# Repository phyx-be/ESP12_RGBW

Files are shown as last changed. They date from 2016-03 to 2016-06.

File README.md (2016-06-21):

# ESP12_RGBW
An ESP12 based RGBW light module using onboard LEDs or capable of controlling external LEDs.

## Rev 00

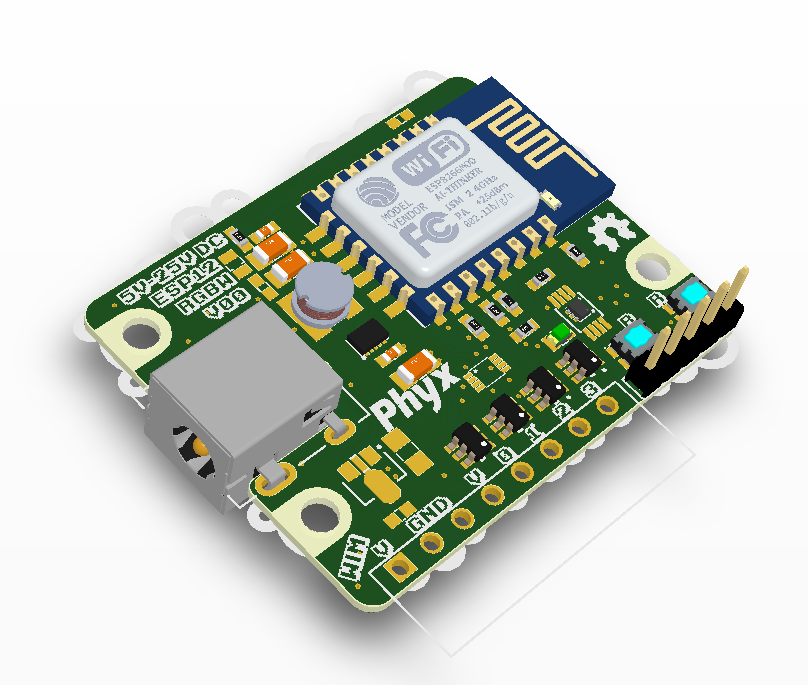
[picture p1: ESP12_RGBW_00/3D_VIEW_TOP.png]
ESP12_RGBW_00_T

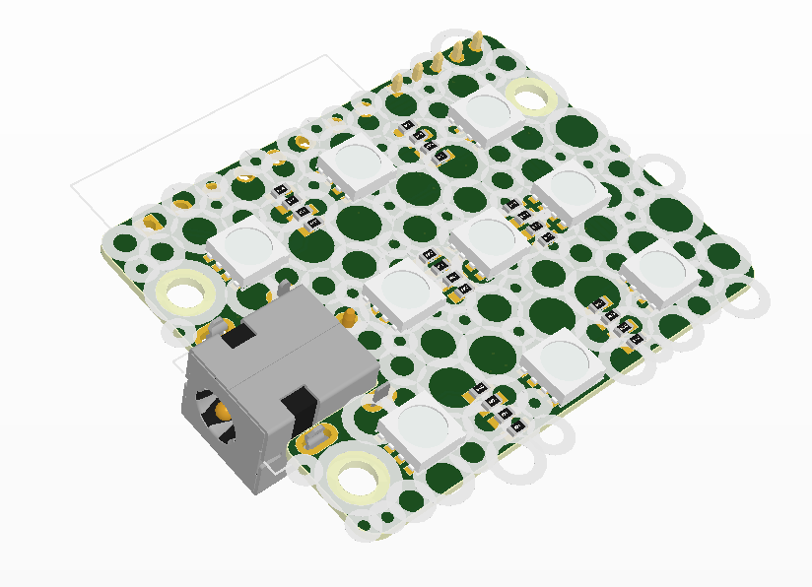
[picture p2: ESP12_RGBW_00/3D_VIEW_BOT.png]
ESP12_RGBW_00_B


### Features

A list of the basic features for the intended use of this board.

- 3V3 level FTDI-compatible UART pin header
- miniature push buttons for reset and boot
- Wide input DC-DC converter (input voltage ranging from 5V to 26V DC)
- 4 FETs capable of sinking 4A
- 3 strings of 3 RGBW LEDs each on the bottom side

### Variants

The board has some options, beside the default configuration with the internal LEDs, which allows you to use the same board for different projects. You'll notice an option for a temperature sensor, bi-directional buffer and pluggable terminal block. More info regarding these options are listed below.

#### Internal LEDs

Default use with either 3, 6 or 9 RGBW LEDs soldered on the bottom side of the PCB. Requires a 12V DC power source. Don't forget to double the resistor values hen using 10mA RGBW LEDs instead of the 20mA LEDs as intended.

#### External LED strips

If you want to drive external RGB or RGBW LED strip you'll have to solder the pluggable terminal block for and you don't need to solder the DC jack and the internal LEDs. If you do opt for a combination of internal and external LEDs, don't forget to match the working voltage of both. By default the internal LEDs require a working voltage of 12V DC.

#### Temperature sensor

You can choose either a 1-Wire [DS18B20](http://www.maximintegrated.com/en/products/analog/sensors-and-sensor-interface/DS18B20.html) temperature sensor or a I2C controlled [Ti TMP112](http://www.ti.com/product/TMP112) temperature sensor. The TMP112 has an higher accuracy.

#### Bi-directional buffer.

Soldering the dual channel bi-directional buffer [TXB0102](http://www.ti.com/product/txb0102) makes it possible for the board to control digital LED strips and strings. This buffer requires a 5V reference which can be created by an internal 5V LDO or by supplying the board with 5V and placing a 0R resistor over the input and output pin of the LDO. Using this option you can no longer add the T1 and T2 FETs, hereby loosing 2 PWM or I/O channels.

## Rev 01

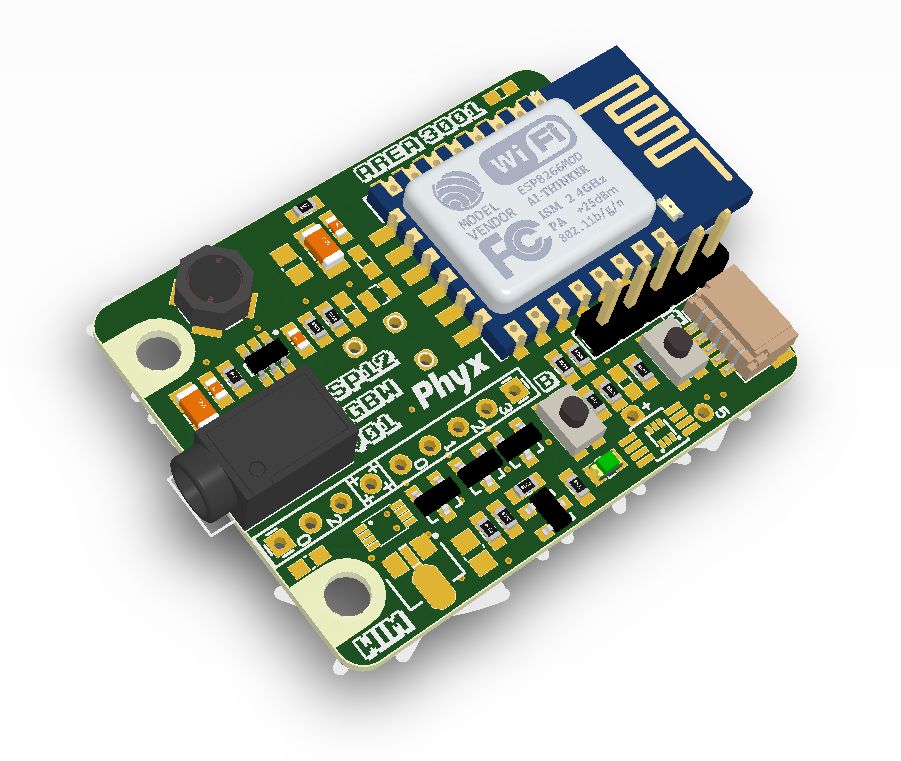
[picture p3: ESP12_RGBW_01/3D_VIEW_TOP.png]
ESP12_RGBW_01_T

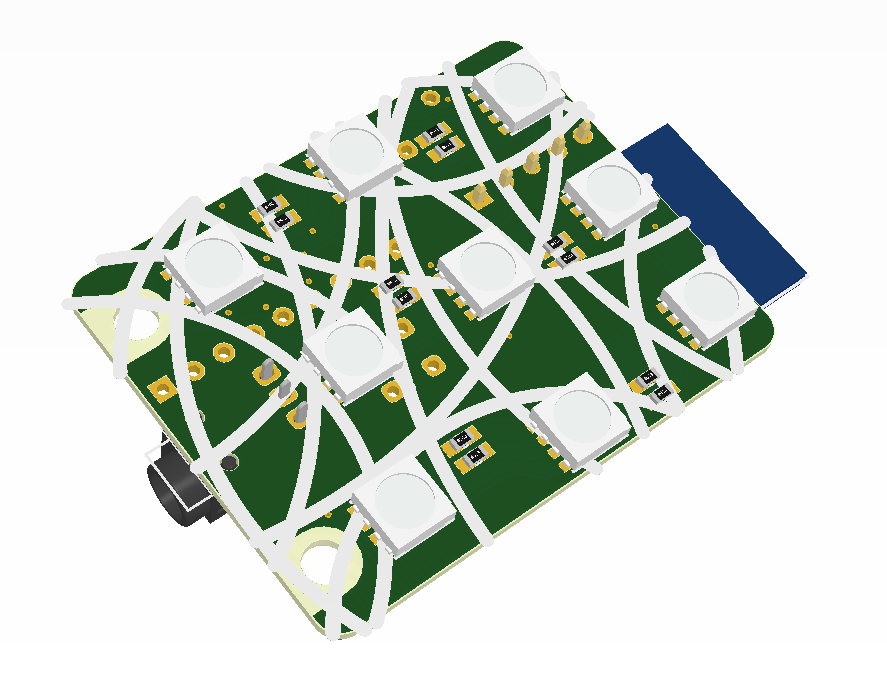
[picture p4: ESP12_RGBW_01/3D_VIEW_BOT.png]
ESP12_RGBW_01_B


This board is a low cost version of the initial board. The main differences include a cheaper power supply, cheaper DC jack and cheaper FETs. This is done whilst trying to maintain as much veratilaty as the initial version. Although you're no longer able to connect a LED strip directly to this board, you do get access to the PWM signals on a 2.54mm header. The max input voltage is now 15V instead of 26. The option for the 5V level translator and temperature sensor have stayed the same. There is an added option for a panasonic [EKMC1601113](http://na.industrial.panasonic.com/products/sensors/sensors-automotive-industrial-applications/pir-motion-sensor-papirs/series/vz-series/2481) PIR motion sensor. The Uart connector now also has the reset and boot signals which allows us to program the boards with a bed of nails. The same signals are available on a 1mm pitch JST header.

### Changes

- Cheaper DC-DC power supply based on the Ti [TPS562209](http://www.ti.com/product/TPS562209)
- Added [EKMC1601113](http://na.industrial.panasonic.com/products/sensors/sensors-automotive-industrial-applications/pir-motion-sensor-papirs/series/vz-series/2481) PIR footprint
- Reduced board size
- Reduced BoM cost
- Smaller DC Jack

## Example use

This board was designed to be used with the [PWM_RGBW branch](https://github.com/area3001/esp8266_lifx/tree/pwm_rgbw) of the [ESP8266_LIFX](https://github.com/area3001/esp8266_lifx) project from [Area 3001](https://github.com/area3001/)

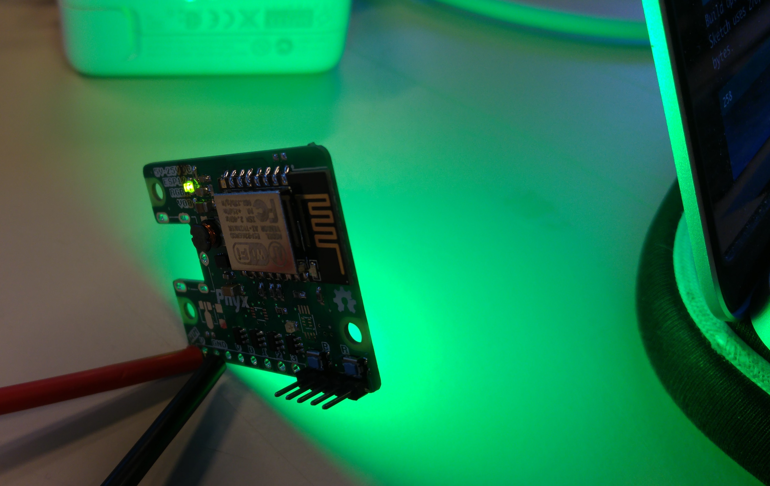
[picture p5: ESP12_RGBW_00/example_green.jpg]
ex_gr


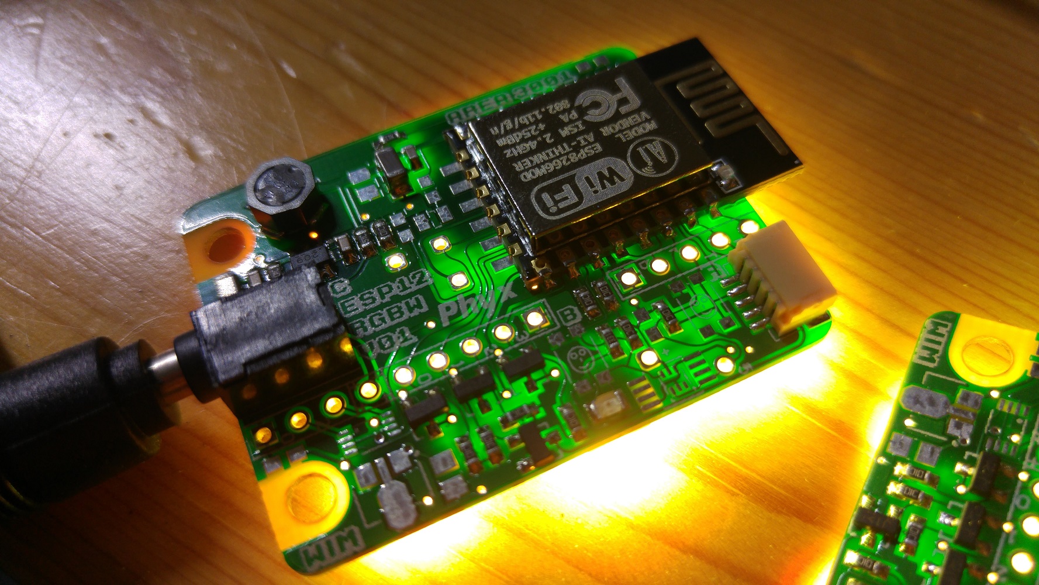
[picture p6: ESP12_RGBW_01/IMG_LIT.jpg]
ex_01


## Assembly pictures

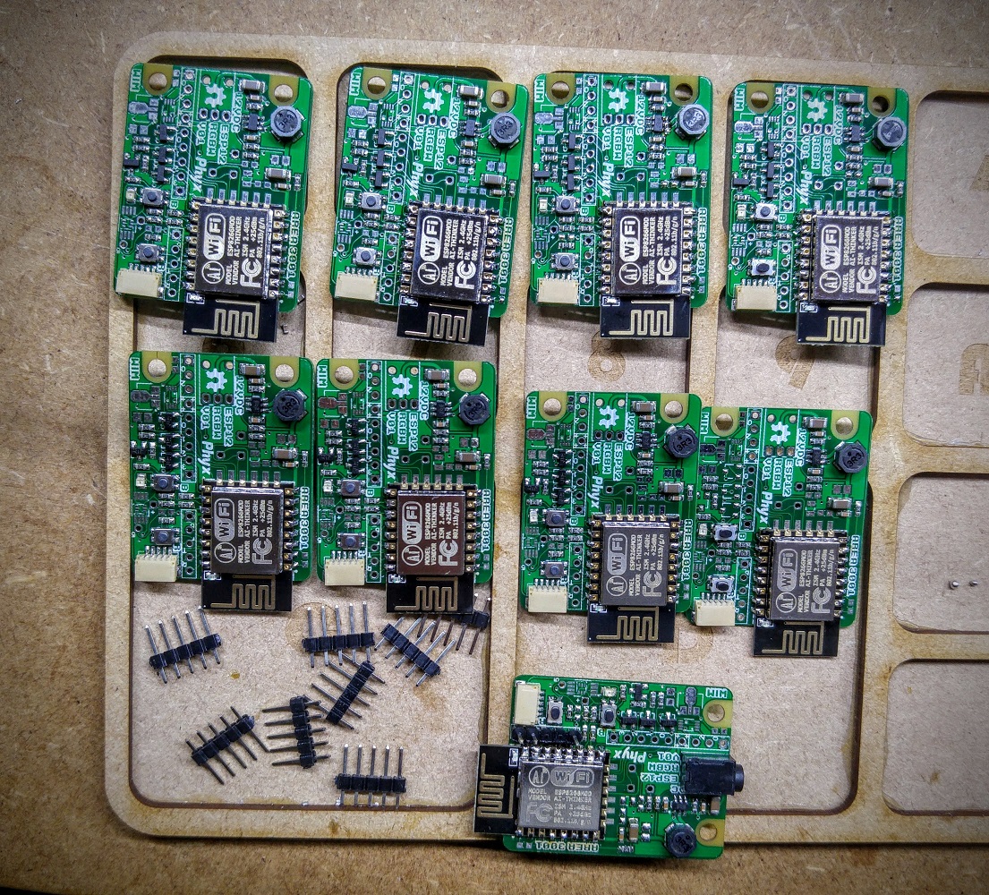
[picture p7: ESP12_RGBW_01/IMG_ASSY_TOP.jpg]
assy_t


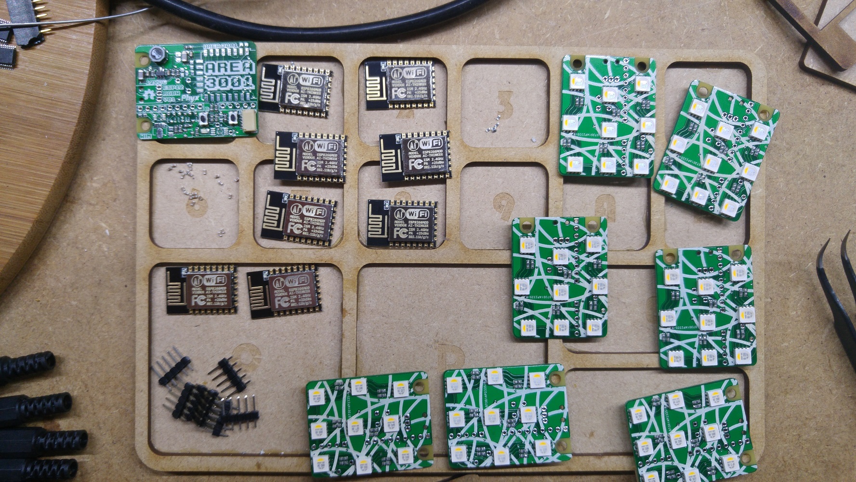
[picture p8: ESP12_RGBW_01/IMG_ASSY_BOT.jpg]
assy_b


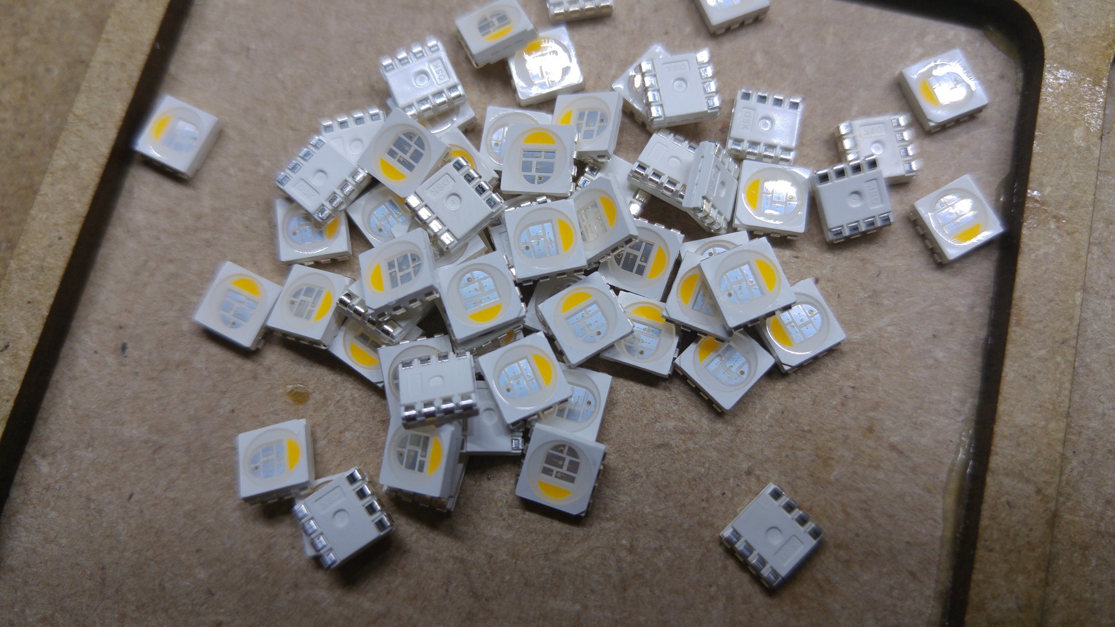
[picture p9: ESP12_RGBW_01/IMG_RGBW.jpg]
assy_rgbw


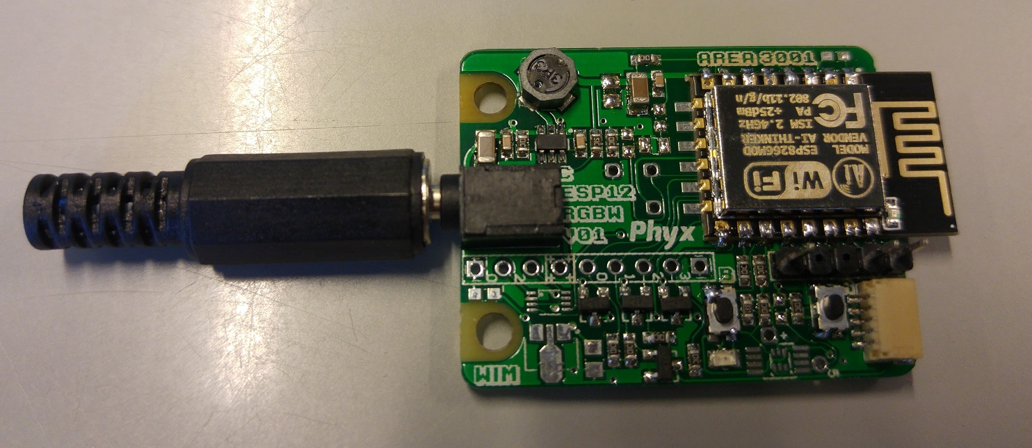
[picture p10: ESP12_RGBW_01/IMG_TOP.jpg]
ex_t


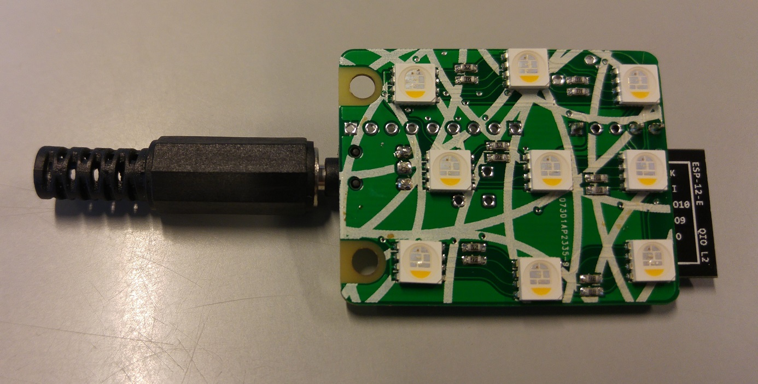
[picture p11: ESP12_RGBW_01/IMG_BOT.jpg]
ex_b


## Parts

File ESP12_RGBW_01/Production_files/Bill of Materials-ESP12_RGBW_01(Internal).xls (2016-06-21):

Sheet: BOM Report
Bill of Materials |  |  | [Internal] of [ESP12_RGBW_01]
Source Data From: |  | ESP12_RGBW_01.PrjPcb
Project: |  | ESP12_RGBW_01.PrjPcb
Variant: |  | Internal
Creation Date: | 2/05/2016 | 16:57:31
Print Date: | 42542 | 42542.89583
Footprint | Comment | LibRef | Designator | Value | Description | Supplier 1 | Supplier Part Number 1 | Quantity
C0603_N |  | CAP # 100nF 50V 0603 | C3, C4, C7 | 100nF 50V | Capacitor Ceramic | Farnell | 1759122 | 3
C1206_N |  | CAP # 22uF 16V 1206 X5R | C6, C9 | 22uF 16V | Capacitor Ceramic | Farnell | 2320923 | 2
LED_0805_GR | Default 0805 Green LED | LED # Green 0805 | D2 |  |  | Farnell | 2099239 | 1
LED_5050_RGBW_PLCC8 | 5050 RGBW LED | LED # RGBW 5050 | D3, D4, D5, D6, D7, D8, D9, D10, D11 | RGBW |  | Aliexpress |  | 9
DC-003 | Socket RA 3.5 with 1.35 barrel | SCKT 1.35mm barrel 3.5mm dia | J1 | DC-003 |  | China |  | 1
BRNS_SRU5028 | SRU5028-3R3Y | IND # 3u3H 5.2x5.2mm | L1 | 3u3H |  | Farnell | 1362085 | 1
ESP-12E | ESP8266 based ESP-12E | WiFi # MOD ESP-12E | MOD1 | ESP-12E |  |  |  | 1
HDR1X5 | Header 5 | Pin Header 2.54mm 5way | P1 |  |  |  |  | 1
WE_665105131822 | Header 1.0mm RA Shrouded 5 | HDR # RA SHR 1.0mm 2way - 665105131822 | P4 | 665105131822 |  |  |  | 1
R0603_N |  | RES # 10K 0603 | R1, R2, R3, R4, R5, R22, R24, R25, R26, R27, R28 | 10K |  | Farnell | 2502397 | 11
R0603_N |  | RES # 270R 0603 | R7, R9, R11, R15, R17, R20 | 270R |  |  |  | 6
R0603_N |  | RES # 560R 0603 | R8, R10, R13 | 560R |  |  |  | 3
R0603_N |  | RES # 330R 0603 | R14, R16, R18, R19 | 330R |  |  |  | 4
R0603_N |  | RES # 33K2 0603 | R23 | 33K2 |  | Farnell | 2331150 | 1
CK_KMR4 | LP SMD tact sw | SW # KMR4 | SW1, SW2 | KMR442GULCLFS |  | Farnell |  | 2
SOT23-3 | 0.2A N-Ch MOSFET Vgs 3.2 | BSS138 N-Ch MOSFET 0.2A 3.2Vgs 60Vds | T1, T2, T3, T4 | BSS138 |  | Farnell | 2432717 | 4
TI_DDC_R-PDSO-G6 | Buck 2A | PWR # Buck TPS562209 2A | U1 | TPS562209DDCT |  | Farnell | 2420236 | 1
 |  |  |  |  |  |  |  | 52
Approved |  | Notes

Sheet: Project Information
Project Full Path | C:\Users\WimVG\Dropbox\Electronics\ESP12_RGBW_01\ESP12_RGBW_01.PrjPcb
Project Filename | ESP12_RGBW_01.PrjPcb
Variant Name | Internal
Data-Source Filename | ESP12_RGBW_01.PrjPcb
Data-Source Full Path | C:\Users\WimVG\Dropbox\Electronics\ESP12_RGBW_01\ESP12_RGBW_01.PrjPcb
Title | Bill of Materials For Variant [Internal] of Project [ESP12_RGBW_01.PrjPcb] (PCB Document : ESP12_RGBW_01.PcbDoc)
Total Quantity | 52
Report Time | 16:57:31
Report Date | 2/05/2016
Report Date & Tine | 2/05/2016 16:57:31
Output Name | Bill of Materials
Output Type | BOM_PartType
Output Generator Name | BOM
Output Generator Description | Bill of Materials

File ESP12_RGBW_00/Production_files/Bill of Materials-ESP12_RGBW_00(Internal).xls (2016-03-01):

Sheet: BOM Report
Bill of Materials |  |  | Variant [Internal]
Source Data From: |  | ESP12_RGBW_00.PrjPcb
Project: |  | ESP12_RGBW_00.PrjPcb
Variant: |  | Internal
Creation Date: | 17/01/2016 | 16:39:44
Print Date: | 42430 | 42430.61859
Footprint | Comment | LibRef | Designator | Value | Description | Supplier 1 | Supplier Part Number 1 | Quantity
C1206_N |  | CAP # 10uF 10V 0805 | C2 | 10uF 10V | Capacitor Ceramic | Farnell | 2320859 | 1
C0603_N |  | CAP # 100nF 50V 0603 | C3, C4 | 100nF 50V | Capacitor Ceramic | Farnell | 1759122 | 2
C1206_N |  | CAP # 22uF 16V 1206 X5R | C11 | 22uF 16V | Capacitor Ceramic | Farnell | 2320923 | 1
C1206_N |  | CAP # 10uF 35V 1206 X5R | C12 | 10uF 35V | Capacitor Ceramic | Farnell | 1797011 | 1
LED_0805_GR | Default 0805 Green LED | LED # Green 0805 | D2 |  | =Description |  |  | 1
LED_5050_RGBW_PLCC8 | 5050 RGBW LED | LED # RGBW 5050 | D3, D4, D5, D6, D7, D8, D9, D10, D11 | RGBW | =Description | Aliexpress |  | 9
694105309102 | Socket RA 4.75 with 1.75 barrel | SCKT 1.75mm barrel in board - 694105309102 | J1 | 694105309102 | SCKT 1.75mm barrel in board - 694105309102 | Farnell |  | 1
BRNS_SDR0503 | SDR0503-100ML | IND # 10uH 5x4.8mm SDR0503-100ML | L1 | 10uH |  | Farnell | 1612675 | 1
ESP-12E | ESP8266 based ESP-12E | WiFi # MOD ESP-12E | MOD1 | ESP-12E | =Description |  |  | 1
HDR1X5 | Header 5 | Pin Header 2.54mm 5way | P1 |  |  |  |  | 1
R0603_N |  | RES # 10K 0603 | R1, R2, R3, R4, R5, R12 | 10K |  |  |  | 6
R0603_N |  | RES # 82R 0603 | R7, R11, R22, R27, R29, R30 | 82R |  | Farnell | 2502484 | 6
R0603_N |  | RES # 68R 0603 | R8, R9, R13, R14, R15, R19, R20, R23, R24, R28, R31, R32 | 68R | GBW LED resistors -> 150R | Farnell | 2502412 | 12
R0603_N |  | RES # 150R 0603 | R10, R16, R17, R21, R25, R26 | 150R | Rode LED resistor -> 300R | Farnell | 2502445 | 6
R0603_N |  | RES # 1K 0603 | R18 | 1K |  |  |  | 1
WE_434153017835 | LP SMD tact sw WS-TASV | SW # TACT mini 3.5x2.9 mm SMD J-Bend WS-TASV | SW1, SW2 | 434153017835 |  |  |  | 2
SOT23-6 | 8A N-Ch MOSFET Vgs 1.9 | SQ3456EV-T1-GE3 N-Ch MOSFET 8A 1.9Vgs 30Vds | T1, T2, T3, T4 | SQ3456EV-T1-GE3 |  | Farnell | 2322581 | 4
TI_DQC_WSON10 | Fixed 3.3V Buck 0.5A | PWR # Buck TPS62177 3.3V 0.5A | U1 | TPS62177DQC | =Description | Farnell | 2255014 | 1
TI_DRL_R-PDSO-N6 | I2C Temp sensor High Accuracy | TEMP # TMP112 | U4 | TMP112 | =Description | Farnell | 1735574 | 1
 |  |  |  |  |  |  |  | 58
Approved |  | Notes

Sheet: Project Information
Project Full Path | C:\Users\Wim\Dropbox\Electronics\ESP12_RGBW_00\ESP12_RGBW_00.PrjPcb
Project Filename | ESP12_RGBW_00.PrjPcb
Variant Name | Internal
Data-Source Filename | ESP12_RGBW_00.PrjPcb
Data-Source Full Path | C:\Users\Wim\Dropbox\Electronics\ESP12_RGBW_00\ESP12_RGBW_00.PrjPcb
Title | Bill of Materials For Variant [Internal] of Project [ESP12_RGBW_00.PrjPcb] (PCB Document : ESP12_RGBW_00.PcbDoc)
Total Quantity | 58
Report Time | 16:39:44
Report Date | 17/01/2016
Report Date & Tine | 17/01/2016 16:39:44
Output Name | Bill of Materials
Output Type | BOM_PartType
Output Generator Name | BOM
Output Generator Description | Bill of Materials

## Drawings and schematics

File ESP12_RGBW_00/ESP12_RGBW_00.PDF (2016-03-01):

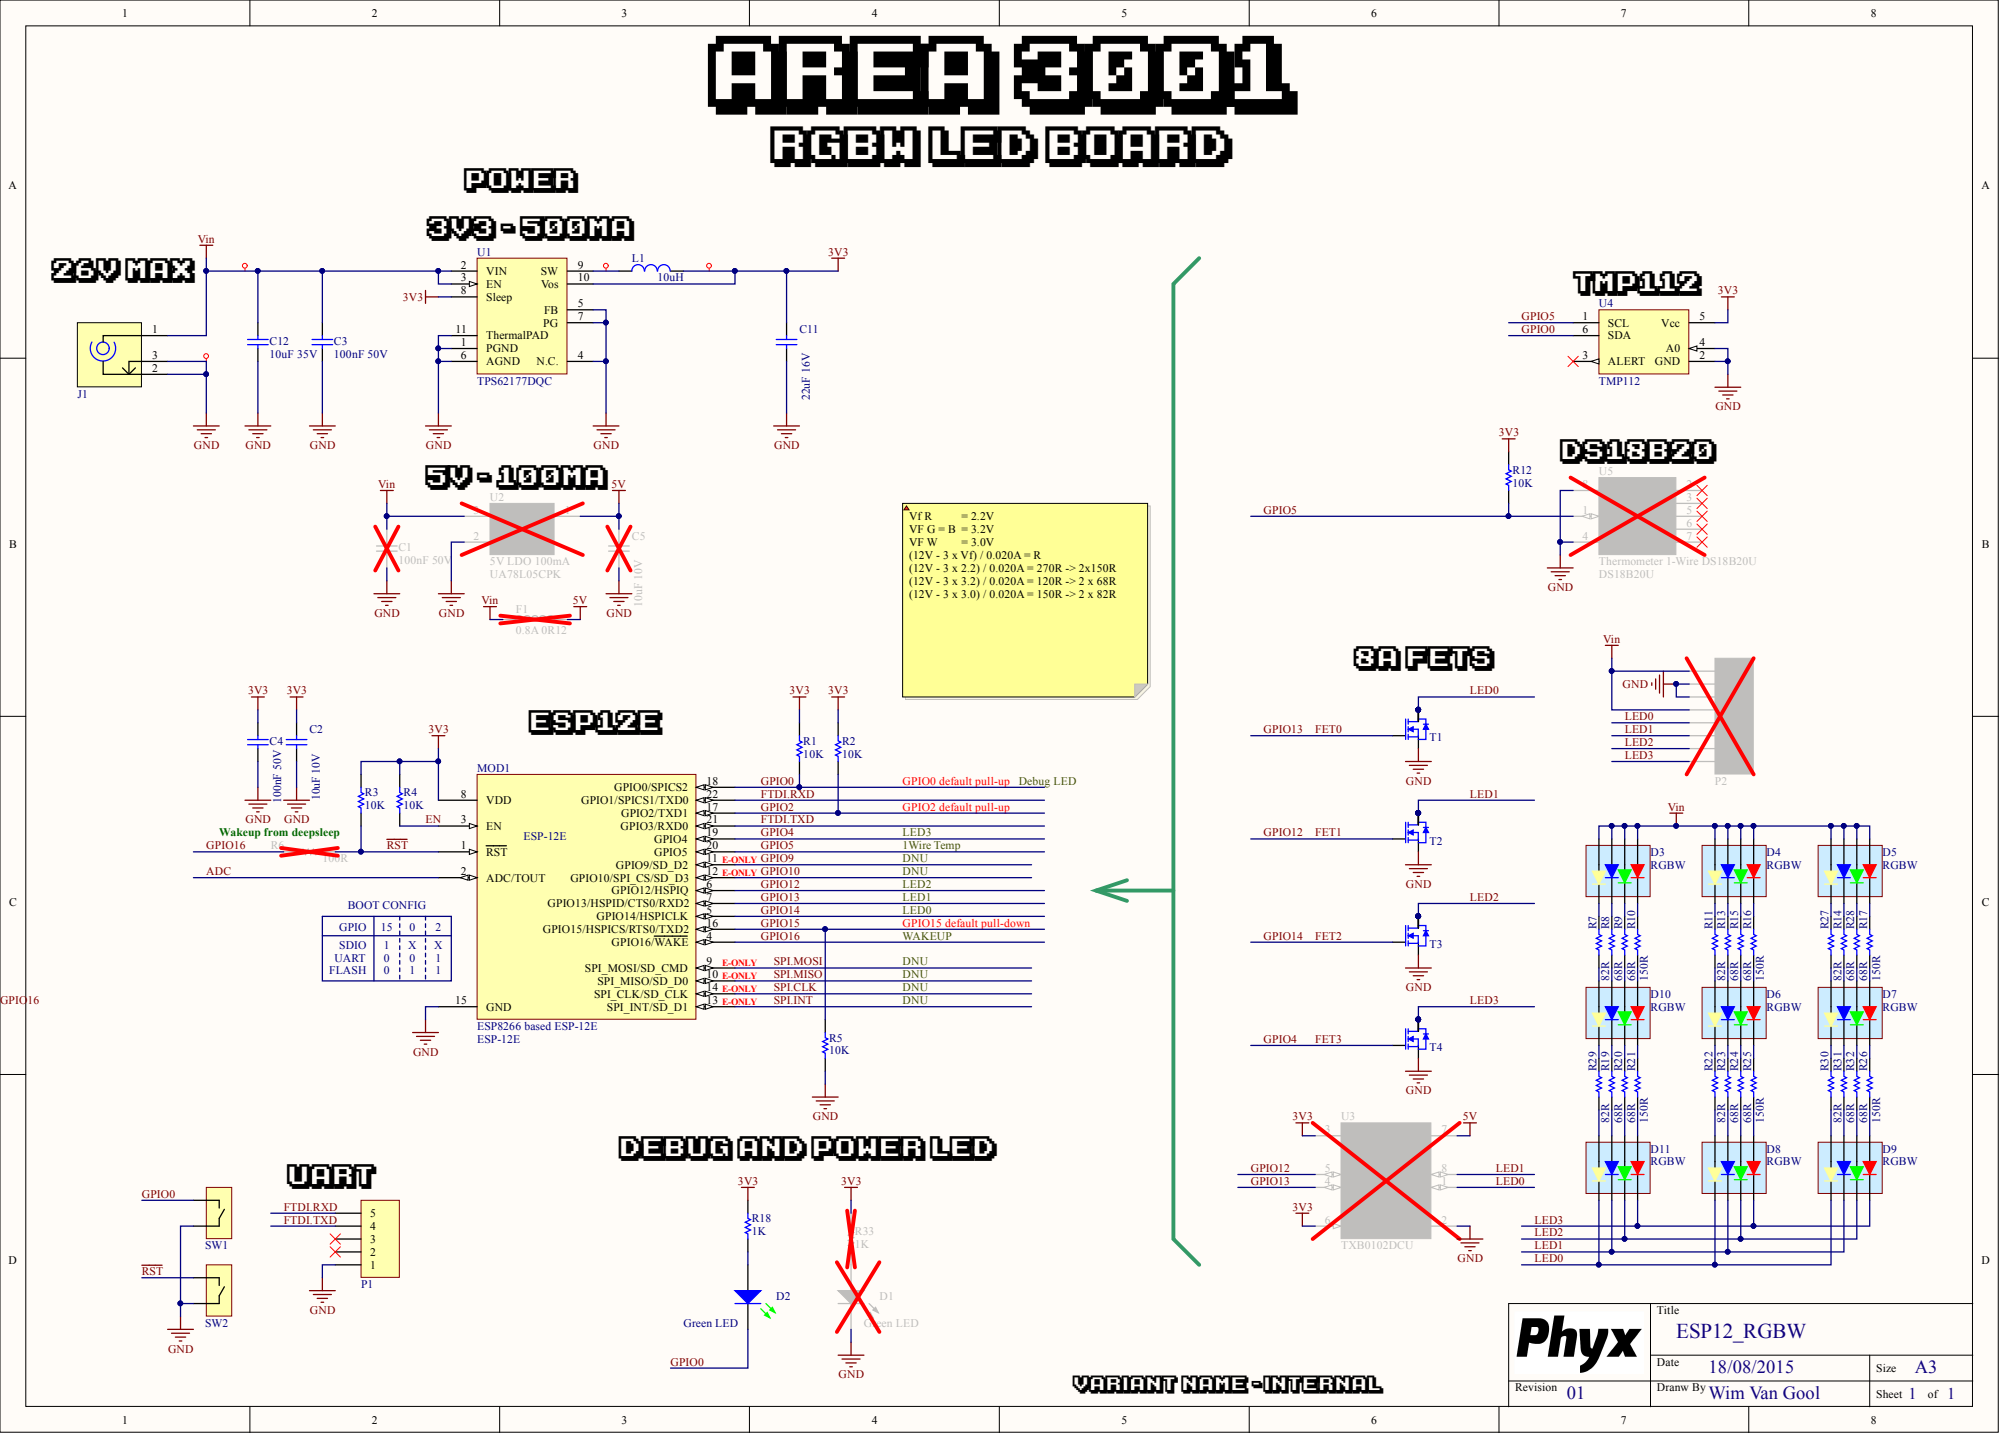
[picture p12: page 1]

GPIO | 1 5 | 0 | 2
SDIO UART FL ASH | 1 0 0 | X 10 | X 1 1

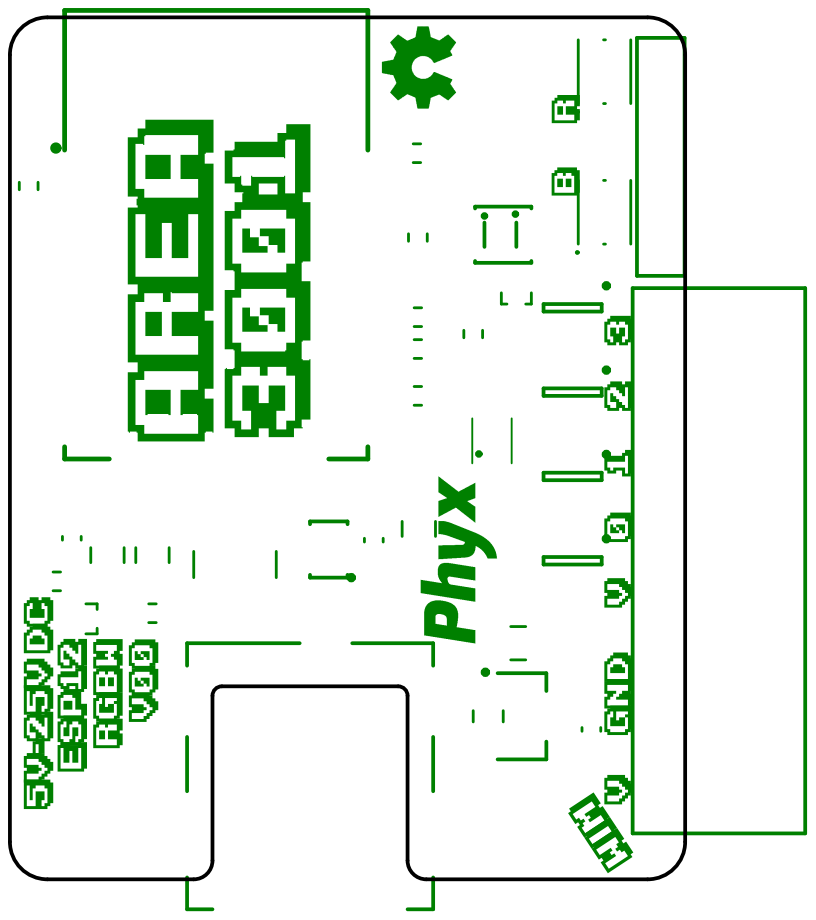
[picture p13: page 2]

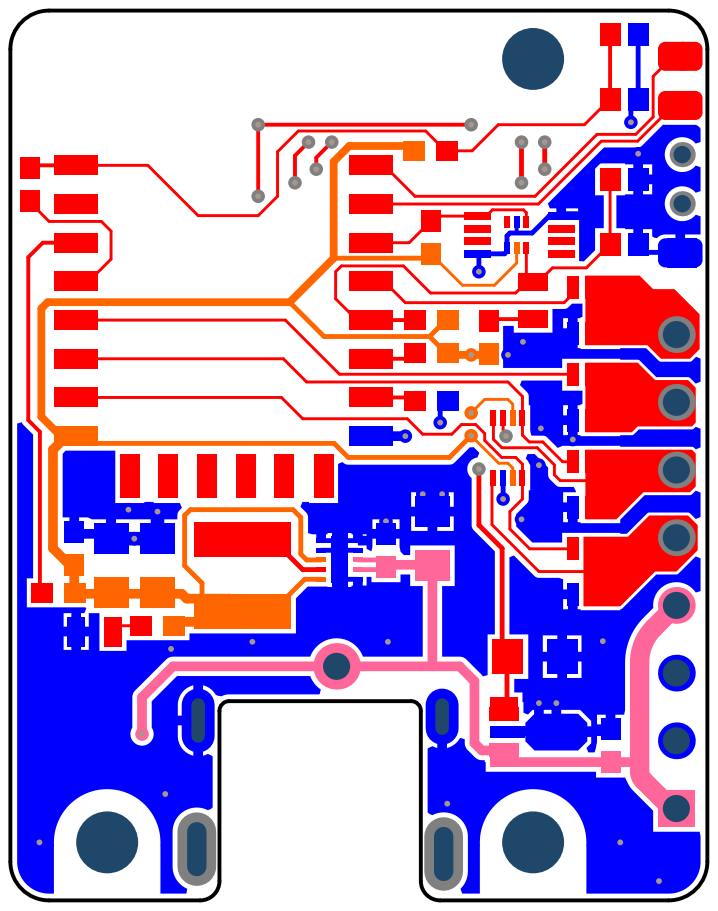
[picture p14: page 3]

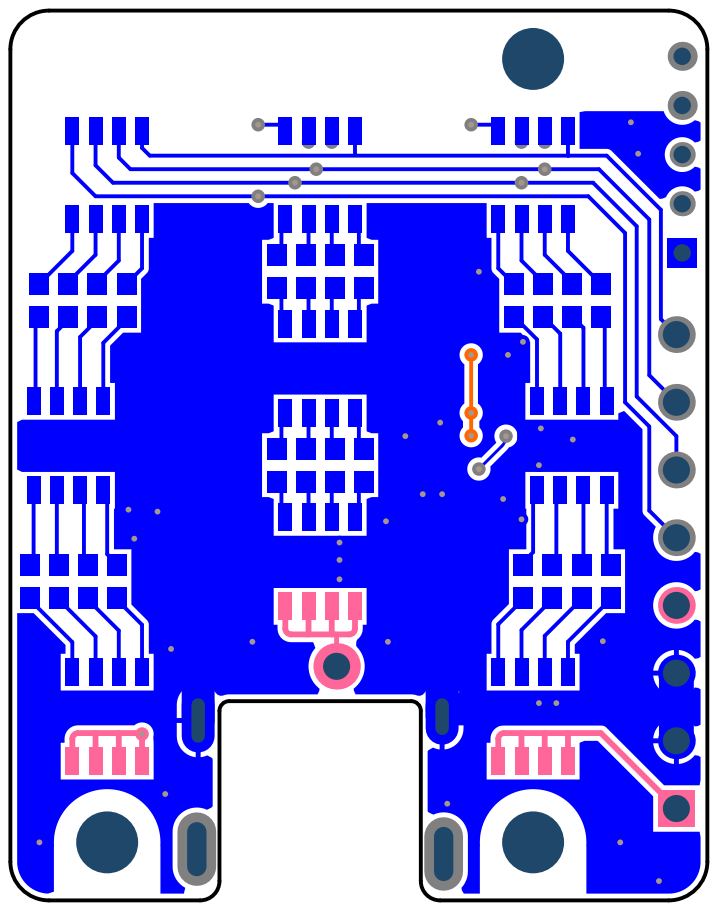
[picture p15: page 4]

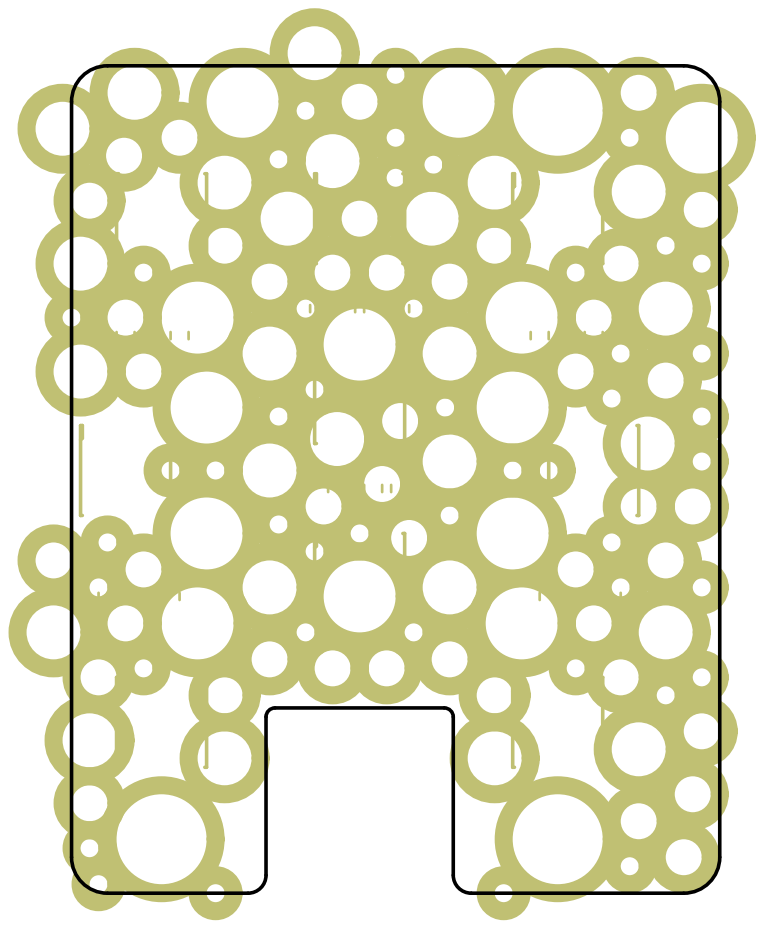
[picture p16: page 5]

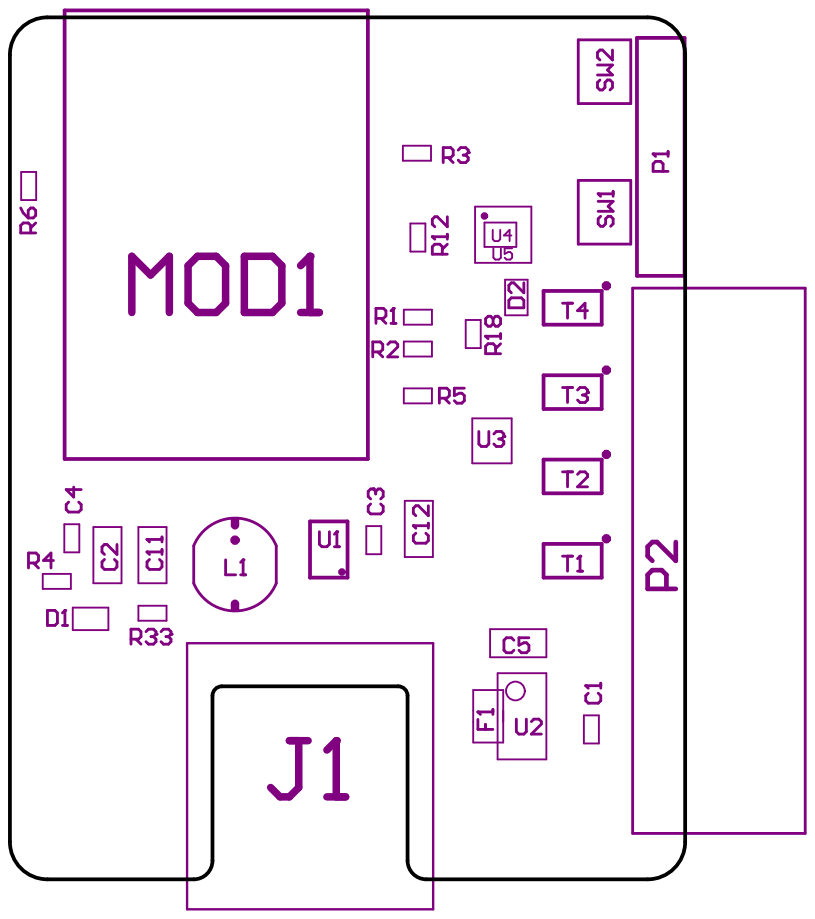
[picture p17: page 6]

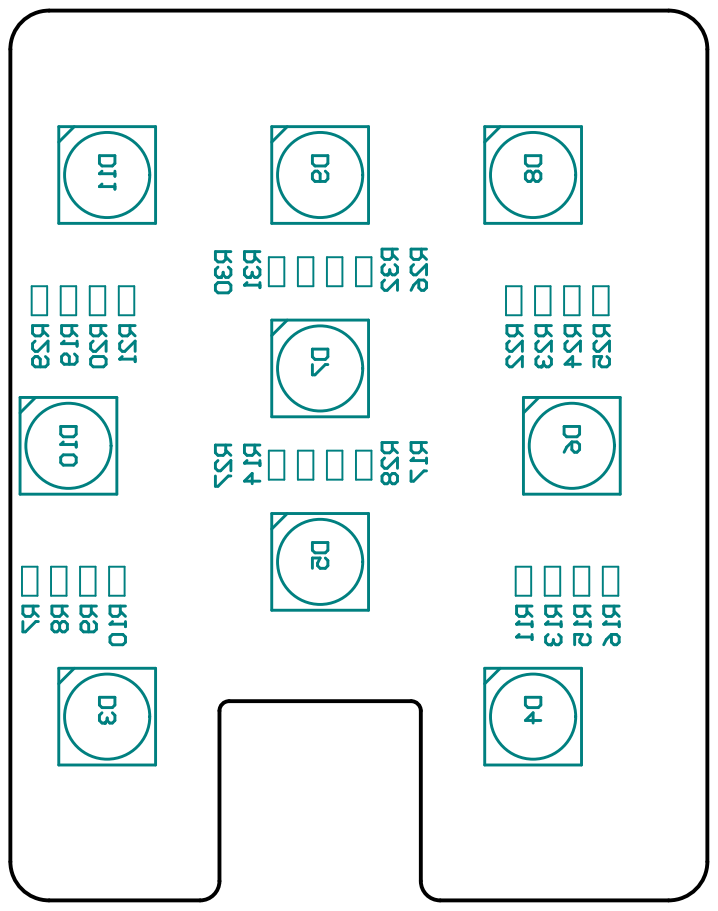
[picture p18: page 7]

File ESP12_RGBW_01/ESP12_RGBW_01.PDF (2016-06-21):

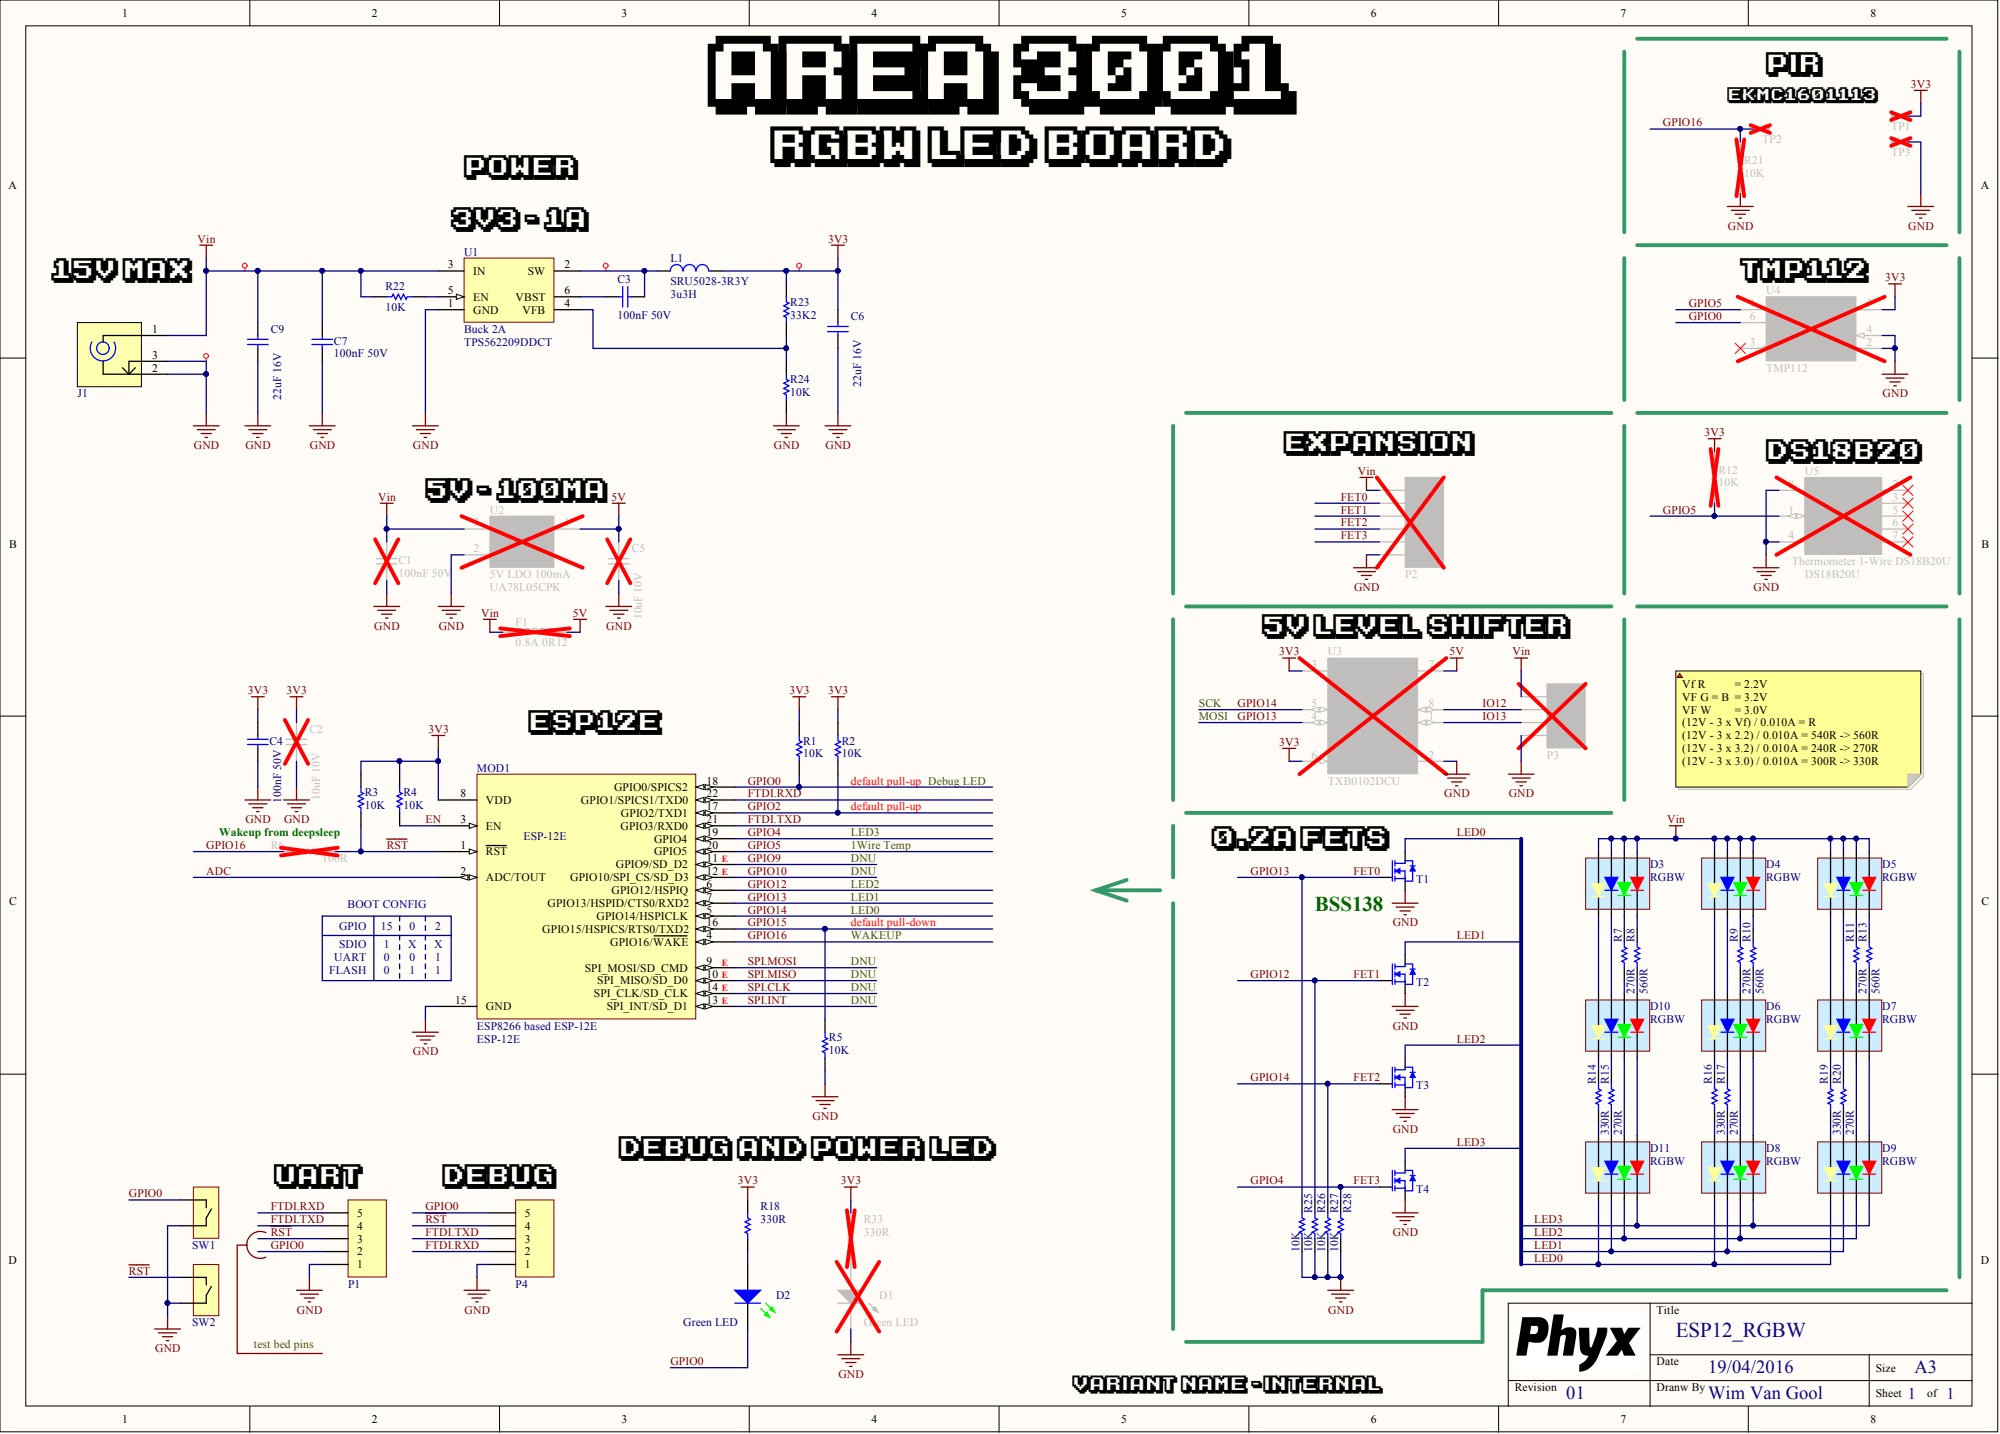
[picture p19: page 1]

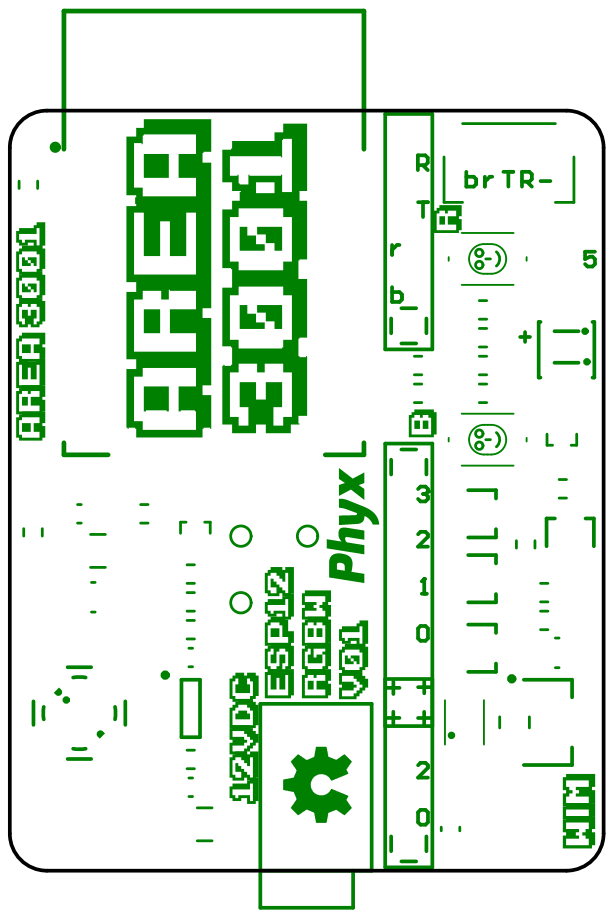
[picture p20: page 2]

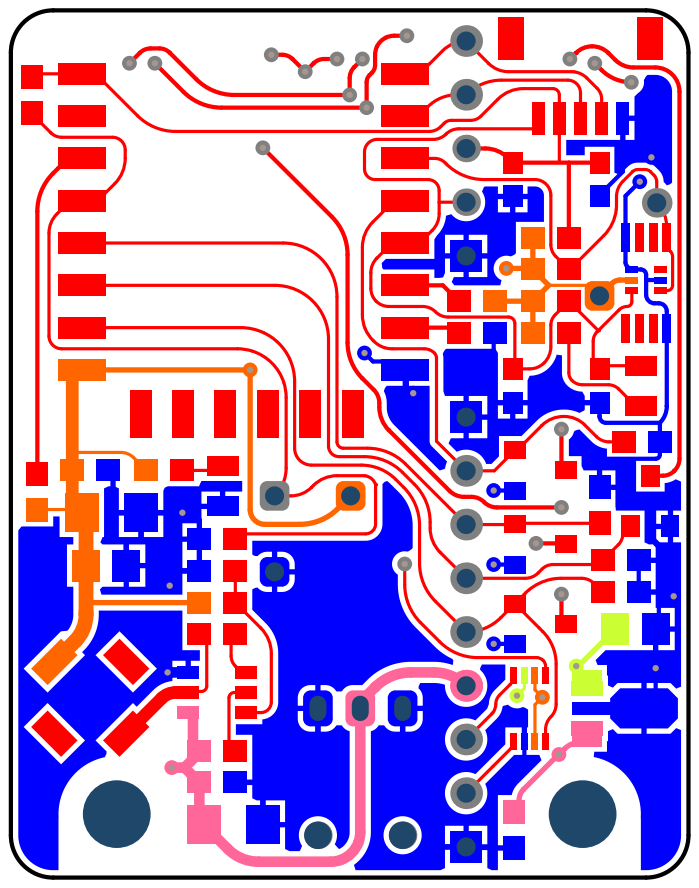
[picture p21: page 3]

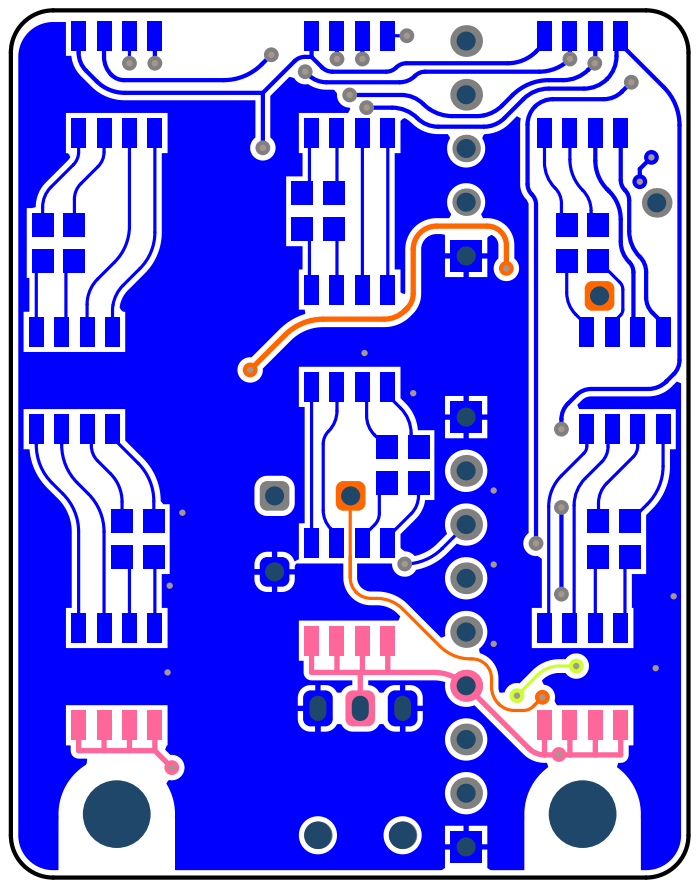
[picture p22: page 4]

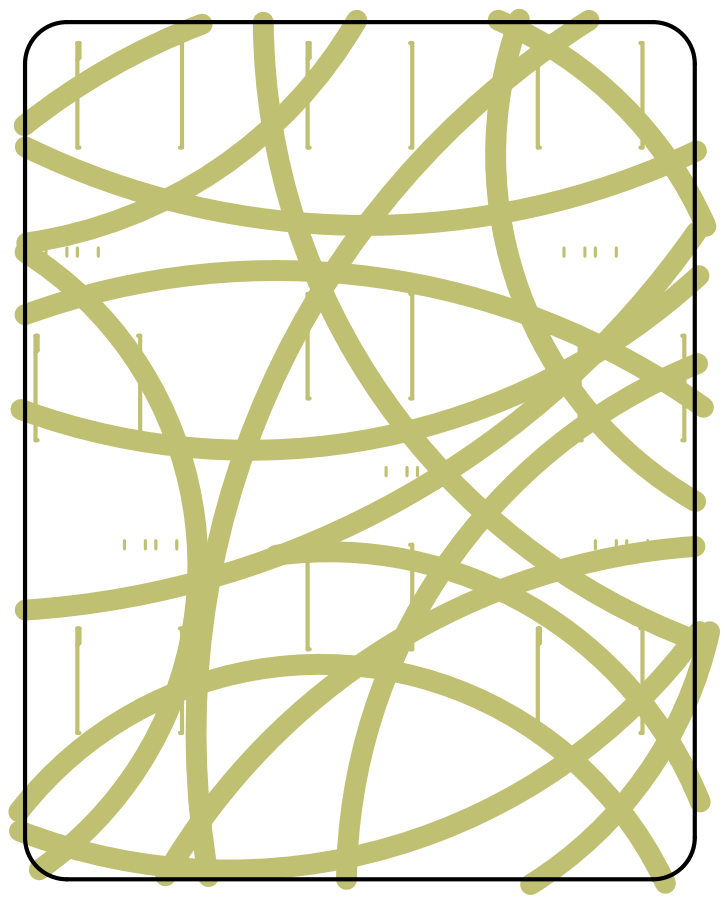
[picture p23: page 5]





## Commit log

2016-03-01 Design files added
    Adde the design and production files for the board. Including a
    preliminary design for a small box.
    [Bill of Materials-ESP12_RGBW_00(Internal).xls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]
2016-06-21 ESP12_RGBW_01 added
    added design files and description of board rev 01
    [Bill of Materials-ESP12_RGBW_01(Internal).xls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]
